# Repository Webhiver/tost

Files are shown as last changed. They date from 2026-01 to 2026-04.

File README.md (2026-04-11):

# PicoThermostat

A DIY smart thermostat system built on the **Raspberry Pi Pico 2W** running MicroPython. Features temperature monitoring, relay control for heating, WiFi connectivity, and a modern web interface.

## Features

- 🌡️ **Temperature & Humidity Monitoring** - DHT22 sensor with sanity checks
- 🔥 **Smart Heating Control** - Configurable hysteresis and safety cutoffs
- 📡 **Multi-Zone Support** - Host/Satellite architecture for multiple rooms
- 🌐 **WiFi Setup** - Easy pairing via captive portal
- 💡 **LED Status Indicators** - RGB LED with priority-based color codes
- 📱 **Modern Web Interface** - Responsive design for mobile & desktop
- ⚡ **Watchdog Timer** - Auto-recovery from system hangs

## Hardware Requirements

### Components

- Raspberry Pi Pico 2W
- DHT22 Temperature & Humidity Sensor
- Relay Module (5V)
- RGB LED (Common Cathode)
- Push Button
- Resistors (for LED limiting)

### Wiring

| Component | GPIO Pin | Notes |
|---|---|---|
| RGB LED Red | GP11 | Use 220Ω resistor |
| RGB LED Green | GP12 | Use 220Ω resistor |
| RGB LED Blue | GP13 | Use 220Ω resistor |
| DHT22 Data | GP28 | Pull-up resistor (4.7kΩ) |
| Relay Signal | GP15 | Active HIGH |
| Button | GP1 | Internal pull-up |

## Installation

### 1. Flash MicroPython

Download and flash the latest MicroPython firmware for Pico W from [micropython.org](https://micropython.org/download/rp2-pico-w/).

### 2. Upload Files

Copy all project files to the Pico using Thonny, rshell, or mpremote:

```
├── main.py
├── hardware_config.py
├── config_manager.py
├── state_manager.py
├── sensor_manager.py
├── led_manager.py
├── relay_manager.py
├── button_manager.py
├── satellite_manager.py
├── pairing_manager.py
├── thermostat.py
├── web_server.py
├── .env/              # Git-ignored config files
│   ├── config.json
│   ├── secrets.json
│   └── env.py
├── lib/
│   ├── microdot.py
│   └── picozero.py
└── app/
    ├── index.html
    ├── styles.css
    └── app.js
```

### 3. First Boot

1. Power on the Pico
2. The LED will blink blue (Pairing Mode)
3. Connect to `PicoThermostat_XXXX` WiFi network
4. Navigate to `192.168.4.1` in your browser
5. Select your home WiFi network and enter password
6. Device will restart and connect to your WiFi

## LED Status Codes

| Priority | Color | State | Meaning |
|---|---|---|---|
| 1 | 🔵 Blue | Blinking | Pairing Mode (AP Active) |
| 2 | 🟡 Yellow | Solid | No WiFi Connection |
| 3 | 🔴 Red | Solid | Heating (Relay Active) |
| 4 | 🟢 Green | Solid | Idle (Connected) |

## Operating Modes

### Host Mode

The primary thermostat controller that:
- Reads local temperature sensor
- Polls satellite sensors
- Controls the heating relay
- Hosts the web interface
- Runs the thermostat algorithm

### Satellite Mode

A remote temperature sensor that:
- Reads local temperature sensor
- Exposes readings via API for host polling
- Shows read-only web interface

## Web API

### Endpoints

| Method | Endpoint | Description |
|---|---|---|
| GET | `/api/status` | Full system status (Host) |
| GET | `/api/readings` | Current sensor data (Satellite) |
| GET | `/api/config` | Get configuration |
| POST | `/api/config` | Replace configuration |
| PATCH | `/api/config` | Partial config update |
| GET | `/api/wifi/scan` | Scan WiFi networks |
| POST | `/api/wifi/connect` | Save WiFi credentials |

### Status Response Example

```json
{
    "config": { ... },
    "is_pairing": false,
    "wifi_connected": true,
    "sensor": {
        "temperature": 21.5,
        "humidity": 45.0
    },
    "flame": false,
    "flame_duration": 0,
    "satellites": [
        {
            "ip": "192.168.1.50",
            "sensor": { "temperature": 20.5, "humidity": 48.0 },
            "online": true
        }
    ]
}
```

## Configuration

### .env/config.json

```json
{
    "mode": "host",
    "target_temperature": 22.0,
    "hysteresis": 1.0,
    "satellites": ["192.168.1.50"],
    "update_interval": 4,
    "satellite_grace_period": 120,
    "led_brightness": 1.0,
    "flame_on_mode": "average",
    "flame_off_mode": "average",
    "local_sensor": "included",
    "max_flame_duration": 14400,
    "flame_cooldown": 1800
}
```

### Configuration Options

| Option | Type | Description |
|---|---|---|
| `mode` | string | `"host"` or `"satellite"` |
| `target_temperature` | float | Target temperature in °C |
| `hysteresis` | float | Temperature buffer to prevent short-cycling |
| `satellites` | array | List of satellite IP addresses |
| `update_interval` | int | Seconds between satellite polls |
| `satellite_grace_period` | int | Seconds before marking satellite offline |
| `led_brightness` | float | LED brightness (0.0 - 1.0) |
| `flame_on_mode` | string | `"average"` or `"all"` for turn-on logic |
| `flame_off_mode` | string | `"average"` or `"all"` for turn-off logic |
| `local_sensor` | string | `"included"` or `"fallback"` |
| `max_flame_duration` | int | Safety cutoff in seconds (4 hours default) |
| `flame_cooldown` | int | Cooldown interval after flame off (30 minutes default) |

## Thermostat Algorithm

### Flame ON Conditions

- **Average Mode**: Turn on if average of all sensors < target - hysteresis
- **All Mode**: Turn on if ALL sensors < target - hysteresis

### Flame OFF Conditions

- **Safety**: Force off if flame_duration > max_flame_duration
- **Average Mode**: Turn off if average > target + hysteresis
- **All Mode**: Turn off if ALL sensors > target + hysteresis

### Local Sensor Rules

- **Included**: Always include local sensor in calculations
- **Fallback**: Only use local sensor if no satellites are online

## Button Controls

- **Long Press (3+ seconds)**: Toggle Pairing Mode

## Safety Features

- ⏱️ **Watchdog Timer**: Auto-resets if system hangs (8 second timeout)
- 🔥 **Max Flame Duration**: Automatic cutoff after 4 hours
- 🌡️ **Sanity Checks**: Ignores readings outside -40°C to 80°C range
- 📡 **Satellite Grace Period**: Continues operation if satellites temporarily offline

## Troubleshooting

### Device won't connect to WiFi
1. Long-press button for 3+ seconds to enter pairing mode
2. Connect to the PicoThermostat access point
3. Re-enter WiFi credentials

### Temperature reading shows "--"
- Check DHT22 wiring
- Ensure pull-up resistor is present on data line
- Sensor may need a moment to warm up

### Relay clicking rapidly
- Increase hysteresis value in settings
- Check for drafts near sensor
- Verify wiring connections

### LED not working
- Check common cathode connection to GND
- Verify resistors are present on each color
- Adjust LED brightness in settings

## Development Setup

### Prerequisites

- [Python 3.11+](https://www.python.org/downloads/)
- A Raspberry Pi Pico 2W connected via USB

### 1. Create a Virtual Environment

```bash
python -m venv .venv
```

Activate it:

- **Windows (PowerShell):** `.venv\Scripts\Activate.ps1`
- **Windows (cmd):** `.venv\Scripts\activate.bat`
- **Windows (Git Bash):** `source .venv/Scripts/activate`
- **Linux / macOS:** `source .venv/bin/activate`

### 2. Install Dependencies

```bash
pip install -r requirements.txt
```

This installs `pyserial`, `textual`, and `mpremote`.

### 3. Run the REPL Tool

```bash
python tools/repl.py
```

This launches a terminal UI (built with [Textual](https://textual.textualize.io/)) that lets you:

- **Connect** to one or more Pico boards over serial (COM ports)
- **Interact** with the MicroPython REPL on each board
- **Deploy** files to the Pico using deploy profiles defined in `deploy.toml`

On startup you'll be prompted to select which COM ports to monitor. Pick the ports corresponding to your connected Picos and the tool handles the rest.

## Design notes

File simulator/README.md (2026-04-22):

# Pico Thermostat Simulator

Node.js simulator that mimics the Pico thermostat's HTTP API. Currently always
runs in **satellite** mode. State and config live in memory only — nothing is
persisted between restarts.

Zero runtime dependencies (just Node's built-in `http`).

All commands below are run from the **project root**.

## Run locally

```bash
npm start --prefix simulator
# or: PORT=9000 node simulator/src/index.js
```

Defaults: `HOST=0.0.0.0`, `PORT=8080` (local), `PORT=80` (Docker image).

The simulator auto-detects the host's primary IPv4 interface at startup and
reports its real IP and MAC in `/api/status`.

## Web UI

A small control panel is served at [`/`](http://localhost:8080/). It shows the
current sensor values plus the device's MAC / IP / firmware version, and has
`+`/`−` buttons (0.1 step) for temperature and humidity, a healthy toggle, and
a message field. It polls `/api/status` every 2s and writes changes via
`PATCH /api/simulator/state/sensor`.

## API

All API responses are JSON.

### Device endpoints (mirror the real firmware)

| Method | Path | Notes |
| --- | --- | --- |
| `GET` | `/` | Web UI (HTML) |
| `GET` | `/api/status` | `{ state, config }` — full device snapshot |
| `GET` | `/api/state` | Trimmed `{ sensor, wifi_strength, firmware_version }` in satellite mode |
| `GET` | `/api/config` | Full config |
| `POST` | `/api/config` | Replace config (in-memory) |
| `PATCH` | `/api/config` | Merge updates into config (in-memory) |
| `GET` | `/api/debug` | Memory/CPU/uptime/flash/system/network info |
| `POST` | `/api/sync` | Accepts `{ flame?, target_temperature?, operating_mode? }`. 403 if not in satellite mode. |
| `GET` | `/api/ping` | Health check |

### Simulator-only endpoints

| Method | Path | Notes |
| --- | --- | --- |
| `POST` | `/api/simulator/state/sensor` | Replace the sensor object |
| `PATCH` | `/api/simulator/state/sensor` | Merge updates into sensor |

Example:

```bash
curl -X PATCH http://localhost:8080/api/simulator/state/sensor \
  -H 'Content-Type: application/json' \
  -d '{"temperature": 18.2}'
```

### `set-sensor.sh` — convenience wrapper

For the sensor endpoint there's a small helper that builds the JSON body for
you and targets a local simulator or a running Docker container.

```bash
simulator/set-sensor.sh --temperature 18.5
simulator/set-sensor.sh --container pico-sat-2 --temperature 22 --humidity 50
simulator/set-sensor.sh --host 192.168.1.201 --port 80 --healthy false --message "Fault"
simulator/set-sensor.sh --replace --temperature 22 --humidity 45 --healthy true --message ""
```

Fields (at least one required):

| Flag | Value |
| --- | --- |
| `--temperature` | Number, °C |
| `--humidity` | Number, % |
| `--healthy` | `true` / `false` (also accepts `1`/`0`, `yes`/`no`) |
| `--message` | String |

Target:

| Flag | Default | Notes |
| --- | --- | --- |
| `--host` | `127.0.0.1` | Target host/IP |
| `--port` | `8080` | Target port |
| `--container` | _(none)_ | Docker container name; resolves IP via `docker inspect` and sets port to 80 |

Mode:

| Flag | Effect |
| --- | --- |
| _(default)_ | `PATCH` — merge the given fields into the current sensor |
| `--replace` | `POST` — replace the whole sensor object |

## Docker

The image is `node:22-alpine` with no install step (zero deps). It listens on
port 80 to match the real device.

```bash
docker build -t pico-sim simulator
docker run --rm -p 8080:80 pico-sim
```

### Running multiple satellites on your LAN (macvlan)

Each container gets its own MAC and LAN IP via a Docker macvlan network. This
is **Linux only** — Docker Desktop on macOS/Windows cannot bridge a macvlan to
the physical LAN.

Use `spawn.sh`:

```bash
# One-time: create the macvlan network (auto-detects parent/subnet/gateway)
export PICOSIM_IP_RANGE=192.168.1.200/28    # reserve a safe slice of your LAN
simulator/spawn.sh network

# Start 5 satellites
simulator/spawn.sh up 5

# Inspect
simulator/spawn.sh list

# Stop & remove containers (keeps the network)
simulator/spawn.sh down

# Remove containers and the network
simulator/spawn.sh clean
```

MACs are assigned deterministically as `${PICOSIM_MAC_PREFIX}:NN` where `NN` is
the satellite index (1-based, hex). Defaults produce `2c:cf:67:00:00:01`,
`2c:cf:67:00:00:02`, … matching the OUI used by the real Pico W hardware.
Because the MACs are pinned, Docker re-uses them across restarts.

Containers are tagged with the label `picosim=true`; `down` and `clean` only
touch labeled containers.

#### Listing container IPs

`docker ps` doesn't show macvlan IPs. Two ways to see them:

```bash
# From the network (one row per attached container)
docker network inspect picolan \
  --format '{{range .Containers}}{{.Name}}	{{.IPv4Address}}	{{.MacAddress}}{{println}}{{end}}'

# From the containers (label-filtered, so only simulator containers)
docker inspect -f '{{.Name}}	{{range .NetworkSettings.Networks}}{{.IPAddress}}	{{.MacAddress}}{{end}}' \
  $(docker ps -q --filter label=picosim=true)
```

#### Script environment variables

| Variable | Default | Purpose |
| --- | --- | --- |
| `PICOSIM_NETWORK` | `picolan` | Docker network name |
| `PICOSIM_IP_RANGE` | _(unset)_ | Required unless `PICOSIM_ALLOW_FULL_SUBNET=1`. Reserve a slice of the LAN (e.g. `192.168.1.200/28`). |
| `PICOSIM_ALLOW_FULL_SUBNET` | _(unset)_ | Set to `1` to use the entire detected subnet (risk of DHCP collisions). |
| `PICOSIM_IMAGE` | `pico-sim` | Image tag |
| `PICOSIM_MAC_PREFIX` | `2c:cf:67:00:00` | First 5 bytes of each MAC |
| `PICOSIM_CONTAINER_PREFIX` | `pico-sat` | Container name prefix |

Max 254 satellites (single-byte MAC suffix).

### docker-compose alternative

`docker-compose.yml` defines three fixed satellites (`pico-sat-1..3`) with
pinned MACs, attached to the same external `picolan` network. Useful when you
want the same devices to come up predictably:

```bash
simulator/spawn.sh network                         # create picolan if it doesn't exist
docker compose -f simulator/docker-compose.yml up --build
```

## Caveats

- **Host ↔ macvlan container traffic is blocked** by a Linux kernel rule. Other
  devices on the LAN can reach the containers; the Docker host itself cannot
  without a macvlan shim interface. Usually fine when you test from another
  machine.
- `/api/debug.flash` and `/api/debug.memory` values come from Node / the host
  OS and aren't meaningful for fidelity — they just fill out the response
  shape so clients don't break.

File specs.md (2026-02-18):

# PicoThermostat Technical Specification v1.1

## 1. Overview

The PicoThermostat is a DIY thermostat system built on the Raspberry Pi Pico 2W. It operates in two modes:

- **Host**: Acts as a central thermostat controller, reading local temperature, managing the relay (heating/cooling), and hosting a web interface.
    
- **Satellite**: Acts as a remote temperature sensor. Will only have one endpoint to read temperature and humidity.

Both modes share a common codebase written in MicroPython.

## 2. Hardware Architecture

### 2.1 Core Components

- **Microcontroller**: Raspberry Pi Pico 2W (WiFi enabled)
    
- **Sensor**: DHT22 (Temperature & Humidity)
    
- **Actuator**: Relay Module
    
- **Interface**:
    
    - RGB LED (Common Cathode) for status indication
        
    - Push Button for user input (Pairing)

### 2.2 Pin Configuration

The hardware pinout definitions will be stored in `hardware_config.py`.

|Component|Pin (GP)|Notes|
|---|---|---|
|**RGB LED Red**|11||
|**RGB LED Green**|12||
|**RGB LED Blue**|13||
|**DHT Sensor**|28|Pull-up resistor required if not on module|
|**Relay**|15|Standard GPIO (do not use onboard LED)|
|**Button**|1||

### 2.3 Wiring

Required wiring.

| Component | Wire Color | Wire Length |
|---|---|---|
| Button | blue | 40mm |
| | black | 40mm |
| Relay | blue | 80mm |
| | black | 80mm |
| | red | 110mm |
| SHT | - | - |

## 3. System States & Feedback

### 3.1 RGB LED Status Codes

The RGB LED provides immediate visual feedback. The status is prioritized; the system displays the color of the **highest priority** active condition.

|Priority|Color|State|Condition|
|---|---|---|---|
|**1**|**Blue**|Blinking|Pairing Mode (Access Point Active)|
|**2**|**Yellow**|Solid|No Network Connection|
|**3**|**Red**|Solid|Flame On (Relay Active / Heating)|
|**4**|**Green**|Solid|Network Connected / Idle (Flame Off)|
|**5**|**Off**|Unpowered|System is off|

### 3.2 Button Interactions

- **Long Press (> 3s)**: Enter/Exit Pairing Mode.

## 4. Operation

### 4.1 Operating Modes

#### Host Mode

- Connects to WiFi.
    
- **Watchdog**: Pets the hardware Watchdog Timer (WDT) every loop iteration. System resets if hung for >8 seconds.
    
- **Polling**: Polls temperature data from a list of known Satellites and reads local sensor.
    
- **Logic**: Executes the Thermostat Control Algorithm (see 4.3).
    
- **Web Server**: Runs `microdot` at `/api` and serves `/app`.

#### Satellite Mode

- Connects to WiFi.
    
- Reads local DHT22 sensor.
    
- Exposes current temperature via `GET /api/readings` for the Host to poll.

### 4.2 Networking & Pairing

- **Pairing Mode**:
    
    - Creates a WiFi Access Point (AP) named `PicoThermostat_XXXX`.
        
    - User connects and provisions WiFi credentials via a simple web page.
        
    - Credentials saved to `.env/secrets.json`.
        
- **Normal Operation**:
    
    - Connects to saved WiFi with credentials from `.env/secrets.json`.

### 4.3 Thermostat Control Algorithm

The Host decides relay state based on aggregated sensor data.

**Definitions:**

- `active_sensors`: List of valid temperature readings from online sources (Satellites + Local).
    
- `read_temp`: The calculated current temperature based on configuration.
    
- `hysteresis`: Buffer to prevent short-cycling.

**Logic Flow:**

1. **Filter Sensors**:
    
    - Exclude Satellites marked `online: false`.
        
    - **Sanity Check**: Ignore local/satellite readings that are `NaN` or unrealistic (e.g., -40°C or >80°C).
        
    - **Local Sensor Rule**:
        
        - If `config.local_sensor == "included"`: Always include local DHT22 in `active_sensors`.
            
        - If `config.local_sensor == "fallback"`: Include local DHT22 _only if_ no Satellites are online.
            
2. **Calculate `read_temp`**:
    
    - If `mode == "average"`: `read_temp = sum(active_sensors) / count(active_sensors)`
        
    - If `mode == "all"`: Treat sensors individually (logic below).
        
3. **Determine Action**:
    
    - **Turn Flame ON** if:
        
        - (`flame_on_mode == "average"`) AND (`read_temp < target_temperature - hysteresis`)
            
        - (`flame_on_mode == "all"`) AND (ALL `active_sensors` are `< target_temperature - hysteresis`)
            
    - **Turn Flame OFF** if:
        
        - **Safety**: `flame_duration > max_flame_duration` (Force Cooldown).
            
        - (`flame_off_mode == "average"`) AND (`read_temp > target_temperature + hysteresis`)
            
        - (`flame_off_mode == "all"`) AND (ALL `active_sensors` are `> target_temperature + hysteresis`)

## 5. Software Architecture

### 5.1 Endpoints

- `GET /api/status`: Returns current state (Host).
    
- `GET /api/readings`: Returns current sensor data `{temperature, humidity}` (Satellite).
    
- `GET /api/config`: Fetch config.
    
- `POST /api/config`: Update config.
    
- `PATCH /api/config`: Partially update config.

### 5.2 Libraries

- `microdot`
    
- `picozero`

### 5.3 Data Structures

**Secrets** (`.env/secrets.json`)

```
{
    "ssid": "Network Name",
    "password": "network password"
}
```

**Config** (`.env/config.json`)

```
{
    "mode": "host", // "host" or "satellite"
    "target_temperature": 22.0,
    "hysteresis": 1.0,
    "satellites": ["192.168.1.5", "192.168.1.6"],
    "update_interval": 4, // Seconds
    "satellite_grace_period": 120, // Seconds
    "led_brightness": 1.0,
    
    // Logic Configuration
    "flame_on_mode": "average", // "average" or "all"
    "flame_off_mode": "average", // "average" or "all"
    "local_sensor": "included", // "included" or "fallback"
    
    // Safety
    "max_flame_duration": 14400 // Seconds (4 hours)
}
```

**State** (Runtime Object)

```
{
    "config": { /* The config object */ },
    "is_pairing": false,
    "sensor": {
        "temperature": 19.5,
        "humidity": 45.0
    },
    "flame": true,
    "flame_start_tick": 120300, // System tick when flame started (for max duration check)
    "satellites": [
        {
            "ip": "192.168.1.5",
            "sensor": {
                "temperature": 20.5,
                "humidity": 44.7
            },
            "last_updated": 230500, // System tick (monotonic)
            "online": true
        }
    ]
}
```

### 5.4 Software Components

- **State Manager**: SSoT.
    
- **Sensor Manager**: Polls local DHT22; applies sanity checks (filters NaN/outliers).
    
- **LED Manager**: Determines color based on Priority Hierarchy (Pairing > Wifi Error > Flame > Idle).
    
- **Relay Manager**: Controls GP15; enforces `max_flame_duration` safety cutoff.
    
- **Button Manager**: Handles pairing toggle.
    
- **Satellite Manager**: Polls satellite IPs; manages `online` status based on `last_updated` ticks vs `grace_period`.
    
- **Pairing Manager**: Manages AP and secrets.
    
- **Config Manager**: JSON I/O. Updates the State when configuration changes.
    
- **Thermostat**: Implements logic from Section 4.3 using `flame_on_mode`/`flame_off_mode`.

## 6. UX / Web Interface

The system serves two distinct web interfaces, written in React in the /app folder. Both are lightweight Single Page Applications (SPAs).

### 6.1 Captive Portal (Pairing Mode)

Served when the device is in AP mode (Blue LED).

- **Goal**: Provision WiFi credentials.
    
- **Features**:
    
    - Scans for available networks (optional, or manual entry).
        
    - Form inputs for SSID and Password.
        
    - "Connect" button that posts credentials to the device.
        
    - Success message upon saving secrets.

### 6.2 Host Application (Normal Operation)

Served when the device is in Host mode and connected to WiFi (Green/Red LED).

- **Goal**: Monitor and control the thermostat.
    
- **Features**:
    
    - **Dashboard**:
        
        - Displays Current Temperature (Large).
            
        - Displays Target Temperature with +/- controls.
            
        - Status Indicator: Heating (Flame icon) vs Idle.
            
        - Humidity display.
            
    - **Settings Panel**:
        
        - List of Satellites (IPs and Status).
            
        - Logic Configuration (Hysteresis, Flame On/Off modes).
            
        - Configurable timers (Grace period, Max flame duration).
            
    - **Satellite View**: If accessed on a Satellite node, displays a read-only view of its local sensor data.

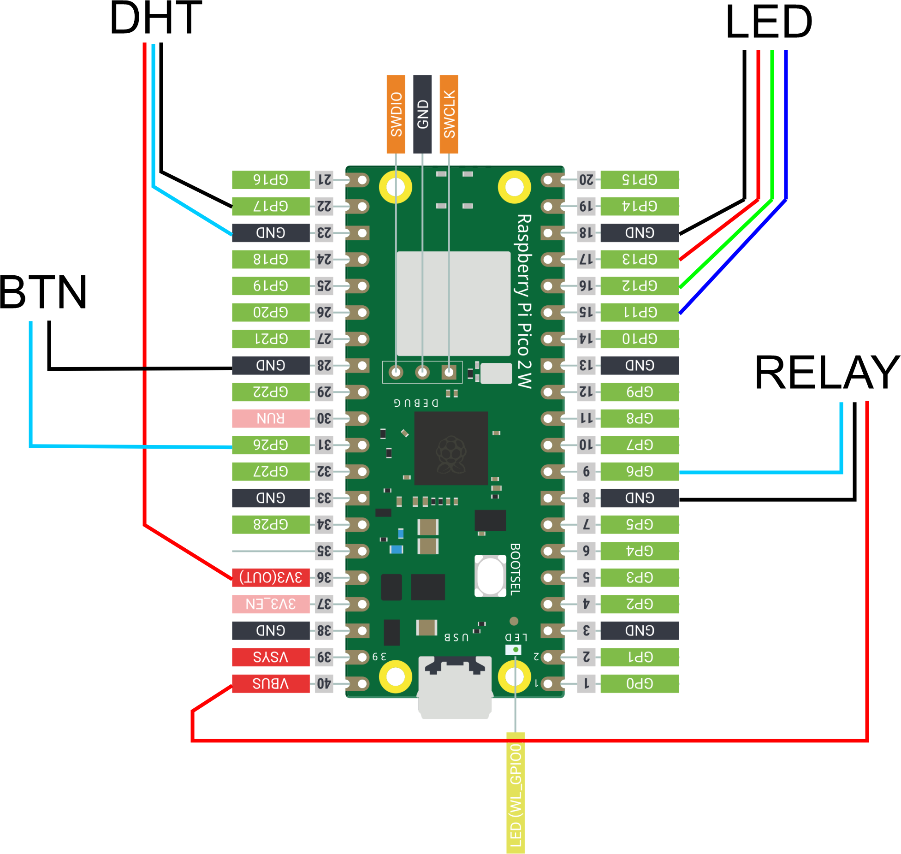
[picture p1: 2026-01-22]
resources/PicoTherm Pinout.png

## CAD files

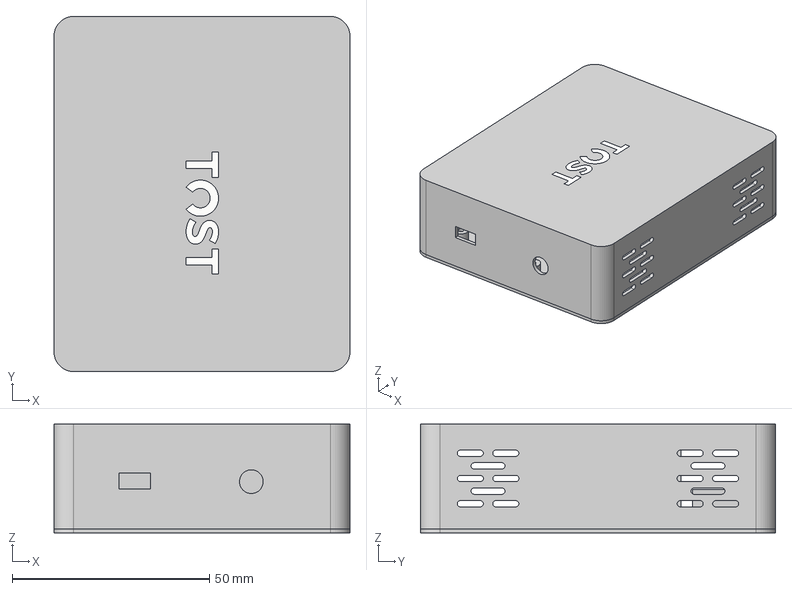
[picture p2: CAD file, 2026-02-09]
resources/PicoTherm case only.step
75.0 x 90.0 x 27.6 mm
Case Base Final SHT4x
Case Lid Final

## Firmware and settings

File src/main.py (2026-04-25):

import asyncio

from config import config
from sensor import sensor
from led import led
from relay import relay
from button import button
from satellite import satellite
from hw_revision import HW_REVISION
from thermostat import thermostat
from temperature import temperature
from web_server import web_server
from dns_server import dns_server
from wifi import wifi
from discovery import discovery
from updater import update_checker
import watchdog


async def main():
    print("PicoThermostat starting...")
    print("HW Revision:", HW_REVISION)

    tasks = [
        asyncio.create_task(watchdog.loop()),
        asyncio.create_task(sensor.loop()),
        asyncio.create_task(led.loop()),
        asyncio.create_task(button.loop()),
        asyncio.create_task(dns_server.loop()),
        asyncio.create_task(wifi.loop()),
        asyncio.create_task(satellite.loop()),
        asyncio.create_task(discovery.loop()),
        asyncio.create_task(web_server.loop()),
        asyncio.create_task(thermostat.loop()),
        asyncio.create_task(update_checker.loop()),
    ]

    # print("PicoThermostat running!")
    print("Mode:", config.get("mode", "host"))

    await asyncio.gather(*tasks)


if __name__ == "__main__":
    try:
        asyncio.run(main())
    except KeyboardInterrupt:
        print("Shutting down...")
        led.off()
        relay.off()

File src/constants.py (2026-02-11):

# Default values (breadboard-dht baseline)
from hw_revision import HW_REVISION

# Hardware pin configuration
PIN_LED_RED = 13
PIN_LED_GREEN = 12
PIN_LED_BLUE = 11
PIN_DHT = 28
PIN_RELAY = 16
PIN_BUTTON = 1
PIN_SHT_SCL = 27
PIN_SHT_SDA = 26

# Sensor type
SENSOR_TYPE = "DHT"

# Network configuration
AP_IP = "192.168.4.1"
AP_SUBNET = "255.255.255.0"
SATELLITE_POLLING_INTERVAL = 5
DISCOVERY_PORT = 5005

# Button configuration
PAIRING_LONG_PRESS_MS = 2000
SHORT_PRESS_MIN_MS = 50      # Minimum press duration (debounce)
SHORT_PRESS_MAX_MS = 500     # Maximum press duration for short press

# Revision-based overrides
if HW_REVISION == "breadboard-dht":
    pass

elif HW_REVISION == "case-dht":
    PIN_BUTTON = 22
    PIN_RELAY = 6

elif HW_REVISION == "breadboard-sht":
    SENSOR_TYPE = "SHT"

elif HW_REVISION == "case-sht":
    PIN_BUTTON = 22
    PIN_RELAY = 6
    SENSOR_TYPE = "SHT"

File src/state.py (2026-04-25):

try:
    from version import VERSION
except ImportError:
    VERSION = "0.0.0"


class StateManager:

    def __init__(self, initial_state=None):
        self._state = initial_state or {}
        self._subscribers = {}

    def get(self, key, default=None):
        return self._state.get(key, default)

    def set(self, key, value):
        old_value = self._state.get(key)
        self._state[key] = value

        if old_value != value:
            self._notify(key, value, old_value)

    def update(self, key, updates):
        current = self._state.get(key, {})
        if isinstance(current, dict) and isinstance(updates, dict):
            old_value = current.copy()
            current.update(updates)
            self._state[key] = current
            self._notify(key, current, old_value)
        else:
            self.set(key, updates)

    def subscribe(self, key, callback):
        if key not in self._subscribers:
            self._subscribers[key] = []

        self._subscribers[key].append(callback)

        def unsubscribe():
            if callback in self._subscribers.get(key, []):
                self._subscribers[key].remove(callback)

        return unsubscribe

    def _notify(self, key, new_value, old_value):
        for callback in self._subscribers.get(key, []):
            try:
                callback(new_value, old_value)
            except Exception as e:
                print("State subscriber error:", e)

    def get_all(self):
        return self._state.copy()

    def set_all(self, state):
        old_state = self._state.copy()
        self._state = state

        all_keys = set(old_state.keys()) | set(state.keys())
        for key in all_keys:
            old_val = old_state.get(key)
            new_val = state.get(key)
            if old_val != new_val:
                self._notify(key, new_val, old_val)

    def get_satellite_state(self):
        """Get trimmed state for satellites (only firmware_version, sensor and wifi_strength)."""
        return {
            "sensor": self._state.get("sensor"),
            "wifi_strength": self._state.get("wifi_strength"),
            "firmware_version": self._state.get("firmware_version"),
            "firmware_update_available": self._state.get("firmware_update_available"),
        }

    def get_satellite_by_mac(self, mac):
        """Find a satellite in state by its MAC address."""
        satellites = self._state.get("satellites", [])
        mac_lower = mac.lower() if mac else ""
        for sat in satellites:
            if sat.get("mac", "").lower() == mac_lower:
                return sat
        return None


state = StateManager({
    "is_pairing": False,
    "wifi_connected": False,
    "wifi_strength": None,
    "mac": None,
    "ip": None,
    "firmware_version": VERSION,
    "firmware_update_available": False,
    "sensor": {
        "temperature": None,
        "humidity": None,
        "healthy": False,
        "message": "Initializing..."
    },
    "flame": False,
    "flame_start_tick": None,
    "flame_cooldown_start_tick": None,
    "flame_duration": 0,
    "satellites": [],
    "effective_temperature": None
})

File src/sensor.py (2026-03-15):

import asyncio
import time
from machine import Pin, I2C
import constants
from state import state
from config import config

# SHT4X I2C constants
_SHT4X_ADDR = const(0x44)
_SHT4X_CMD_MEASURE_HIGH = const(0xFD)
_SHT4X_MEASURE_WAIT_MS = const(10)
_SHT4X_CRC_POLY = const(0x31)
_SHT4X_CRC_INIT = const(0xFF)


def _sht4x_crc(data):
    """Compute CRC-8 checksum per Sensirion spec."""
    crc = _SHT4X_CRC_INIT
    for byte in data:
        crc ^= byte
        for _ in range(8):
            if crc & 0x80:
                crc = (crc << 1) ^ _SHT4X_CRC_POLY
            else:
                crc = crc << 1
    return crc & 0xFF


class SensorManager:
    
    MIN_TEMP = -40.0
    MAX_TEMP = 80.0
    MIN_HUMIDITY = 0.0
    MAX_HUMIDITY = 100.0
    
    def __init__(self):
        self._sensor_type = constants.SENSOR_TYPE
        # print(f"Sensor: Using {self._sensor_type} sensor")
        if self._sensor_type == "SHT":
            self._i2c = I2C(1,
                            scl=Pin(constants.PIN_SHT_SCL),
                            sda=Pin(constants.PIN_SHT_SDA),
                            freq=100000)
        else:
            import dht
            self._sensor = dht.DHT22(Pin(constants.PIN_DHT, Pin.IN, Pin.PULL_UP))
        self._last_temp = None
        self._last_humidity = None
    
    def _read_dht(self):
        """Read temperature and humidity from DHT22 sensor."""
        import dht  # already imported at init, but guard for clarity
        self._sensor.measure()
        return self._sensor.temperature(), self._sensor.humidity()
    
    def _read_sht(self):
        """Read temperature and humidity from SHT4X sensor over I2C."""
        self._i2c.writeto(_SHT4X_ADDR, bytes([_SHT4X_CMD_MEASURE_HIGH]))
        time.sleep_ms(_SHT4X_MEASURE_WAIT_MS)
        buf = self._i2c.readfrom(_SHT4X_ADDR, 6)
        
        # Verify CRC for temperature bytes
        if _sht4x_crc(buf[0:2]) != buf[2]:
            raise OSError("SHT4X temperature CRC mismatch")
        # Verify CRC for humidity bytes
        if _sht4x_crc(buf[3:5]) != buf[5]:
            raise OSError("SHT4X humidity CRC mismatch")
        
        t_ticks = buf[0] * 256 + buf[1]
        rh_ticks = buf[3] * 256 + buf[4]
        
        temp = -45.0 + 175.0 * t_ticks / 65535.0
        humidity = -6.0 + 125.0 * rh_ticks / 65535.0
        
        return temp, humidity
    
    def read(self):
        try:
            if self._sensor_type == "SHT":
                temp, humidity = self._read_sht()
            else:
                temp, humidity = self._read_dht()
            
            temp_valid = self._is_valid_temp(temp)
            humidity_valid = self._is_valid_humidity(humidity)
            
            if not temp_valid:
                temp = None
            if not humidity_valid:
                humidity = None
            
            # Apply offsets from config
            if temp is not None:
                temp_offset = config.get("sensor_temperature_offset", 0.0)
                temp = round(temp + temp_offset, 1)
            if humidity is not None:
                humidity_offset = config.get("sensor_humidity_offset", 0.0)
                humidity = round(humidity + humidity_offset, 1)
                # Clamp humidity to valid range after offset
                humidity = max(self.MIN_HUMIDITY, min(self.MAX_HUMIDITY, humidity))
            
            self._last_temp = temp
            self._last_humidity = humidity
            
            # Determine health status
            if temp is None and humidity is None:
                return temp, humidity, False, "No valid readings"
            elif temp is None:
                return temp, humidity, False, "Invalid temperature"
            elif humidity is None:
                return temp, humidity, False, "Invalid humidity"
            else:
                return temp, humidity, True, ""
            
        except OSError as e:
            return None, None, False, "Sensor read error"
    
    def _is_valid_temp(self, temp):
        if temp is None:
            return False
        try:
            if temp != temp:
                return False
            return self.MIN_TEMP <= temp <= self.MAX_TEMP
        except (TypeError, ValueError):
            return False
    
    def _is_valid_humidity(self, humidity):
        if humidity is None:
            return False
        try:
            if humidity != humidity:
                return False
            return self.MIN_HUMIDITY <= humidity <= self.MAX_HUMIDITY
        except (TypeError, ValueError):
            return False
    
    @property
    def last_temperature(self):
        return self._last_temp
    
    @property
    def last_humidity(self):
        return self._last_humidity

    async def loop(self):
        while True:
            temp, humidity, healthy, message = self.read()
            state.set("sensor", {
                "temperature": temp,
                "humidity": humidity,
                "healthy": healthy,
                "message": message
            })
            await asyncio.sleep(2)


sensor = SensorManager()

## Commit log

2026-01-15 Initial commit
    Add PicoThermostat project files including thermostat logic, web server,
    sensor management, and web app interface.
2026-01-15 Add delayed device reset after saving Wi-Fi credentials
    [web_server.py]
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2026-01-18 Refactor thermostat: replace `loop` with `start` method, add hysteresis toggle in state updates
    [main.py, thermostat.py]
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2026-01-18 Extend sensor data structure and propagate health status to Dashboard
    - Add `healthy` boolean and `message` string to `SensorData` type.
    - Update sensor manager to calculate and return sensor health and status messages.
    - Modify satellite manager to handle sensor health data in polling and state updates.
    - Enhance Dashboard UI to display sensor health status and error messages.
    [satellite_manager.py, sensor_manager.py, state_manager.py]
2026-01-18 Add sensor calibration offsets for temperature and humidity
    - Add UI components in Settings for temperature and humidity offset adjustments.
    - Update `config_manager` to include default offset values.
    - Modify `sensor_manager` to apply configured offsets during temperature and humidity readings.
    - Ensure humidity values are clamped to a valid range after applying offsets.
    - Update `types.ts` to include new config properties.
2026-01-18 Remove `update_interval` configuration and replace with `SATELLITE_POLLING_INTERVAL` constant
    - Eliminate `update_interval` from settings, types, and default configuration.
    - Introduce `SATELLITE_POLLING_INTERVAL` constant in `network_config.py` for satellite polling.
    - Update `SatelliteManager` to use the new constant for polling intervals.
    [satellite_manager.py]
2026-01-18 Restrict satellite-specific settings to host mode in the Settings UI
    - Wrap temperature control, timing, and satellite sections with a conditional to hide them when in satellite mode.
    - Ensure a cleaner, mode-specific configuration experience in the UI.
2026-01-18 Add support for remote satellite configuration in Settings UI
    - Introduce satellite-specific configuration through a new `Settings` UI flow.
    - Add `fetchSatelliteConfig` and `updateSatelliteConfig` API functions for remote updates.
    - Extend `Settings` component to handle satellite targets with dynamic loading, error handling, and retry logic.
    - Update `Dashboard` to include satellite-specific settings access.
    - Refactor settings handling to differentiate between host and satellite contexts.
2026-01-18 Track and expose flame duration in state and improve duration formatting
    - Add `flame_duration` to thermostat state for tracking.
    - Update `formatDuration` to display hours, minutes, and seconds.
2026-01-18 Refactor SatelliteManager to use asyncio and enable concurrent satellite polling
    - Replace synchronous satellite polling with asynchronous methods (`poll_satellite_async`, `poll_all_satellites_async`).
    - Remove `urequests` dependency and implement `asyncio.open_connection` for HTTP requests.
    - Introduce timeout handling and improved error management for satellite polling.
    - Refactor polling loop to support concurrent execution without blocking.
    [satellite_manager.py]
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2026-01-18 Add WiFi strength tracking and display in UI
    - Introduce `NetworkManager` to track WiFi signal strength (RSSI) and convert it to a strength level (0-4).
    - Add `wifi_strength` to the global state and `types.ts` for status persistence.
    - Update `Header` component to display a WiFi signal icon based on `wifi_strength`.
    - Pass `wifi_strength` to `Dashboard` and `SatelliteView` for status updates.
    - Register `NetworkManager` in the main asyncio loop for periodic strength updates.
2026-01-19 Debounce target temperature slider updates in Dashboard for smoother feedback and reduced API calls
2026-01-19 Introduce fetch cancellation and polling reset for status updates
    - Add support for aborting in-flight status fetches to prevent race conditions.
    - Implement polling interval reset mechanism after config updates for improved reliability.
    - Update Dashboard interactions to integrate fetch cancellation and polling reset flows.
2026-01-19 Replace temperature display sections with compact device health cards and reorganize Dashboard and SatelliteView layouts
2026-01-19 Skip flame change handling in satellite mode in RelayManager
    [relay_manager.py]
2026-01-19 Refactor `/api/debug` handling to offload logic into `debug_manager` module
    - Extract debug information gathering into dedicated `debug_manager.py` for improved modularity and maintainability.
    - Replace in-line logic in `/api/debug` endpoint with a call to `get_debug_info()`.
    [web_server.py]
2026-01-19 Add support for theme switching and system-based theming
    - Introduce `useTheme` hook for managing light, dark, and system themes.
    - Add global CSS variables for theme colors and implement both light and dark themes.
    - Update UI components (`Pairing`, `Dashboard`, `Settings`) to use theme variables.
    - Implement a `ThemeSelector` in `Settings` for user-controlled theme switching.
    - Ensure dark mode preference is applied immediately to prevent UI flashes.
    - Refactor Tailwind configuration to utilize CSS variables for theme colors.
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2026-01-20 Refactor captive portal route handling in `web_server.py`
    - Replace `CAPTIVE_PORTAL_PATHS` list with individual route definitions for improved clarity and accessibility.
    - Ensure captive portal requests are served correctly during pairing mode.
    [web_server.py]
2026-01-20 Refactor and standardize state and config management
    - Replace inline state and config access with `state_manager` and `config_manager` abstractions across modules for consistency and maintainability.
    - Refactor `ConfigManager` to include pub-sub mechanism, `set_all`, `update_all`, and streamlined file operations.
    - Update `Thermostat`, `SatelliteManager`, `RelayManager`, and others to leverage subscriptions for state/config updates.
    - Simplify `main.py` initialization by removing redundant state/config loading logic.
    - Ensure consistent use of `state_manager` and `config_manager` in route handlers, removing individual state/config passing.
    [dns_server.py, led_manager.py, main.py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]
2026-01-20 Refactor status handling by introducing `state` abstraction
    - Add `State` interface to encapsulate pairing, flame, sensor, and satellite-related properties.
    - Update `Status` interface to include nested `state` and `config` for clearer separation of concerns.
    - Refactor all modules and components (`Dashboard`, `SatelliteView`, `useStatus`, etc.) to access status properties through `state`.
    - Standardize config update callbacks for improved type safety (`Config` instead of `Status['config']`).
2026-01-20 Refactor WiFi and pairing management
    - Introduce `WiFiManager` to encapsulate WiFi initialization and connection logic.
    - Simplify pairing mode handling by subscribing to `is_pairing` state changes in `PairingManager`.
    - Remove redundant WiFi connection and pairing logic from `ButtonManager` and `main.py`.
    - Consolidate WiFi credential handling and connection retries using `secrets` in `WiFiManager`.
2026-01-20 Refactor WiFi and flame state management
    - Subscribe to `is_pairing` state changes in `WiFiManager` for streamlined WiFi connection handling.
    - Simplify flame duration tracking by integrating `flame_start_tick` updates into `Thermostat`.
    - Remove redundant methods and unused imports in `RelayManager` and `ConfigManager` for cleanup.
    - Eliminate WiFi state management duplication in `PairingManager`.
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2026-01-21 Remove `/api/readings` route and update satellite sensor data mapping
    - Eliminate `/api/readings` endpoint from `web_server.py` to streamline API.
    - Update `satellite.py` to fetch sensor data via `/api/status` and adjust data parsing for nested `sensor` structure.
2026-01-21 Refactor satellite data handling to store full `state` and update references
    - Replace `sensor` field with full `state` object in satellite data.
    - Adjust API polling in `satellite.py` to retrieve and manage nested `state` structure.
    - Update `Dashboard` and related components to access nested sensor properties through `state`.
    [satellite.py, thermostat.py]
2026-01-21 Add save status indicators and timers to `Settings` component
    - Introduce save result display with timers for success/error messages.
    - Add `isSaving` and `saveResult` states for better save status visibility.
    - Adjust debounce duration and ensure consistent teardown of timers.
2026-01-21 Add support for short press to reboot device and refactor elapsed time calculation
    - Introduce reboot functionality on short button press (50-500ms duration).
    - Extract `_get_elapsed` method to handle tick overflow and simplify logic.
    - Update constants to include short press timing thresholds.
    [button.py, constants.py]
2026-01-21 Validate IP addresses and improve satellite configuration handling
    - Add `isValidIp` function to validate IPv4 addresses and ensure proper format.
    - Improve local state handling in `Settings` for adding, updating, and removing satellites with immediate feedback.
    - Filter satellites with invalid IPs before queuing updates to the server.
    - Highlight invalid IPs with an error state in the UI for better user feedback.
    - Add `_sanitize_satellites` function in `config` to ensure only valid satellite IPs are saved.
    [config.py]
2026-01-21 Add `flame_mode` and `flame_mode_sensor` settings with UI and type support
    - Introduce `flame_mode` and `flame_mode_sensor` fields in `Config`.
    - Add corresponding dropdowns to `Settings` for managing `flame_mode` and its specific sensor.
    - Update default config and types to incorporate new `FlameMode` options.
2026-01-21 Add `effective_temperature` calculation and display
    - Introduce `TemperatureCalculator` class to compute `effective_temperature` based on state and config variables.
    - Update types and state to include `effective_temperature` field.
    - Display `effective_temperature` in the `Dashboard` with fallback handling for null values.
    - Refactor satellite and local temperature display to improve structure and clarity.
2026-01-21 Remove support for `flame_on_mode` and `flame_off_mode`
    - Replace `active_sensors` handling with `effective_temperature` for flame control logic.
    - Eliminate config fields `flame_on_mode` and `flame_off_mode` along with associated UI elements.
    - Update `Thermostat` methods to use `effective_temperature` directly for simplicity and improved performance.
    [config.py, thermostat.py]
2026-01-22 Add 3MF file for PicoTherm model
    [PicoTherm.3mf]
2026-01-22 Update PicoTherm STEP file to v15 with revised dimensions and geometry adjustments
    [PicoTherm.3mf, PicoTherm.step]
2026-01-22 Add `env.py.example` for configurable environment overrides
    - Provide an example `env.py` file for hardware pins, network, and button configuration.
    - Update `constants.py` to allow overrides from `env.py` if present.
    - Add `src/env.py` to `.gitignore` to prevent accidental commits.
    [constants.py]
2026-01-22 Update PicoTherm STEP files
    [PicoTherm case only.step, PicoTherm.3mf, PicoTherm.step]
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2026-01-23 Switch to `calcKnobArcPathRounded` for smoother arc rendering, adjust context default values, and enhance touch event handling.
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2026-01-25 Switch satellites from IP-based to MAC-based identification
    - Update the system to use MAC addresses as primary identifiers for satellites.
    - Replace IP validation with MAC validation and normalization across the backend and frontend.
    - Adjust logic for discovery, settings, and state management to accommodate MAC-based identification.
    - Update types, UI components, and placeholder texts to reflect the shift to MAC addresses.
    [config.py, satellite.py, state.py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]
2026-01-25 Update PicoTherm components step files
    [PicoTherm case only.step]
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2026-01-26 Fix status text in devices slider
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2026-02-07 Refine `SettingsPanel` LED Brightness label to display percentage dynamically and prevent event propagation in `Field` component.
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2026-02-09 Update case 3D models for SHT4x sensors.
    [PicoTherm case only.step]
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2026-02-12 Add validation for device config inputs in `PanelsProvider` and display errors in UI
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2026-02-17 Add POST `/api/reboot` endpoint to schedule device reboot asynchronously
    [web_server.py]
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2026-02-17 Add support for device reboot functionality in `PanelsProvider` and `SettingsPanel`
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2026-03-12 Add a multi-pane serial monitor TUI for connected devices
    - Implement `SerialMonitorApp` for monitoring multiple serial devices in a split-pane interface.
    - Add `PortSelectionScreen` modal for COM port selection.
    - Include support for serial log display, command input, and control character sending.
    - Handle connection retries and disconnections gracefully.
    - Add keyboard shortcuts for pane navigation and common serial actions.
    [repl.py]
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2026-03-15 Refactor WiFi, discovery, and satellite management
    - Simplify WiFi connection logic by removing blocking behavior and redundant checks.
    - Overhaul discovery to replace synchronous device detection with event-driven announcements (`DISCOVER` and `IAM` messages).
    - Deprecate satellite discovery on WiFi connect; IP updates now triggered via broadcast responses.
    - Optimize satellite state synchronization for cleaner code and improved maintainability.
    - Adjust loops and timeouts for more efficient operation.
    [discovery.py, satellite.py, sensor.py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]
2026-03-15 Refactor WiFi, WebServer, and Watchdog modules; add RSSI strength calculation
    - Consolidate WiFi reconnection logic and add signal strength conversion to a utility method.
    - Refactor WebServer into a class-based architecture for cleaner route handling and initialization.
    - Introduce a new Watchdog module for periodic reset prevention, integrated with the main event loop.
    - Remove redundant logic in pairing and discovery; streamline network scan results.
    [discovery.py, dns_server.py, main.py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]
2026-03-15 Refactor discovery for event-driven announcements and optimized UDP broadcast handling
    - Replace one-shot sockets with persistent UDP socket for broadcasting.
    - Add `_needs_announce` flag to manage announcement state more effectively.
    - Simplify `_broadcast` logic by using the main listening socket.
    [discovery.py]
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2026-03-16 Add broadcast address property to WiFi module and improve network broadcast handling
    - Introduce `broadcast_address` property in `WiFi` for subnet-directed broadcasts.
    - Update discovery to use dynamic broadcast addresses instead of hardcoded ones.
    - Ensure AP interface is reset properly when stopping pairing mode.
    - Add DNS server stop notification for better debugging.
    [discovery.py, dns_server.py, pairing.py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]
2026-04-11 Add flame cooldown feature to prevent flame quick on/off/on behavior
    [config.py, thermostat.py]
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2026-04-18 Add flame_cooldown_start_tick to initial state and import version file with fail-safe fallback
    [state.py]
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2026-04-24 Fix Monitoring panel layout to support multiple devices.
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2026-04-26 Adjust discovery jitter and poll intervals, improve error handling in message loop
    [discovery.py]
2026-04-26 Implement satellite polling batching to limit concurrent operations and prevent TCP socket exhaustion
    [satellite.py]
